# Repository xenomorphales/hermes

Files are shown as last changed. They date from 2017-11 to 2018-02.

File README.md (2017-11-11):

# Hermes

Hermes is a rolling base board that drives motors and gets feedback from encoders, IR distance sensors and limit switches.

Warning: before opening any file from this KiCad project, make sure to have a path set in KiCad (Preferences > Configure Paths) named XENOCAD and pointing to the KiCad subdirectory of our [xenocad repository](https://github.com/xenomorphales/xenocad).

[Back to our main project](https://github.com/xenomorphales/xenomorphales)

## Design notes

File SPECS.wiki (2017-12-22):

== Devices ==

{|
!  Device !! Quantity !! Links !! Comment
|-
| Main board
| 1
| [https://www.pjrc.com/store/teensy32.html Board]
| Teensy 3.2
|-
| Motor 30A fuse
| 1
| [https://www.mouser.fr/ProductDetail/Bussmann-Eaton/BK-ABC-V-30-R/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 Axial fuse]
|
|-
| 5V regulator
| 1
| [https://www.mouser.fr/ProductDetail/Murata-Power-Solutions/OKI-78SR-5-15-W36-C/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 Regulator]
| Murata OKI78SR5/1.5W36C
|-
| Regulator 1A fuse
| 1
| [https://www.mouser.fr/ProductDetail/Bussmann-Eaton/BK-GMA-1-R/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 Fuse] <br/>
[https://www.mouser.fr/ProductDetail/Littelfuse/64600001003/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 Fuse holder]
|
|-
| Encoder
| 2
| [http://www.robotshop.com/eu/fr/encodeur-rotatif-6mm-1024-p-r.html Encoder]
|
|-
| Motor driver
| 2 channels
|
[https://www.pololu.com/product/708 Driver] <br/>
[http://www.francerobotique.com/moteurs-classiques/567-moteur-metal-planetaire-premium-hd-12v-612rpm-avec-encodeur-art0567-servocitypoids-330g-rapport-de-reduction-14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 Motors]
|
|-
| Limit switch
| 4
|
| With debounce system
|-
| GP2
| 6
|
|
|-
| CAN
| 1
| [https://www.mouser.fr/ProductDetail/Texas-Instruments/SN65HVD232DR/?qs=sGAEpiMZZMuo%252bmZx5g6tFL5kWJ52EgZi Transceiver]
|
|-
| UART
| 2
|
|
|-
| I2C
| 1
|
|
|-
| Debug LED
| 3
| [https://www.mouser.fr/ProductDetail/Kingbright/AP3216CGCK/?qs=VdjlWU%2FzoOG1eeDl%2FnjAXA%3D%3D LED]
| Green LED
|-
| Pull
| 1
|
| With debounce system
|-
| Power LED
| 2
| [https://www.mouser.fr/ProductDetail/Kingbright/AP3216SURCK/?qs=sGAEpiMZZMseGfSY3csMkfJS7xWFNN5n33Jv6PCAEQU%3D LED]
| Red LED (one for +15V, one for +5V)
|-
|}

== Pin mapping ==

{|
!  Board pin !! µC pin index !! µC pin name !! Mode        !! I/O !! Feature
|-
|  0         || 39           || PTB16       || UART0_RX    || I   || UART 0 input
|-
|  1         || 40           || PTB17       || UART0_TX    || O   || UART 0 output
|-
|  2         || 57           || PTD0        || PTD0        || I   || Pull
|-
|  3         || 28           || PTA12       || CAN0_TX     || O   || CAN ouput
|-
|  4         || 29           || PTA13       || CAN0_RX     || I   || CAN input
|-
|  5         || 64           || PTD7        || PTD7        || I   || Limit switch 1
|-
|  6         || 61           || PTD4        || PTD4        || I   || Limit switch 2
|-
|  7         || 59           || PTD2        || PTD2        || I   || Limit switch 3
|-
|  8         || 60           || PTD3        || PTD3        || I   || Limit switch 4
|-
|  9         || 46           || PTC3        || UART1_RX    || I   || UART 1 input
|-
|  10        || 49           || PTC4        || UART1_TX    || O   || UART 1 output
|-
|  11        || 51           || PTC6        || PTC6        || O   || LED Debug0
|-
|  12        || 52           || PTC7        || PTC7        || O   || LED Debug1
|-
|  13        || 50           || PTC5        || PTC5        || O   || LED Debug2 ; On-board LED
|-
|  14        || 58           || PTD1        || ADC0_SE5b   || I   || GP2 1
|-
|  15        || 43           || PTC0        || PTC0        || I   || Motor driver 1 diag input
|-
|  16        || 35           || PTB0        || FTM1_QD_PHA || I   || Encoder 1 phase A
|-
|  17        || 36           || PTB1        || FTM1_QD_PHB || I   || Encoder 1 phase B
|-
|  18        || 38           || PTB3        || I2C0_SDA    || I/O || I2C data
|-
|  19        || 37           || PTB2        || I2C0_SCL    || I/O || I2C clock
|-
|  20        || 62           || PTD5        || ADC0_SE6b   || I   || GP2 2
|-
|  21        || 63           || PTD6        || ADC0_SE7b   || I   || GP2 3
|-
|  22        || 44           || PTC1        || FTM0_CH0    || O   || Motor driver 1 PWM output
|-
|  23        || 45           || PTC2        || FTM0_CH1    || O   || Motor driver 2 PWM output
|-
|  A10       || 9            || ADC0_DP0    || ---         || --- || ---
|-
|  A11       || 10           || ADC0_DM0    || ---         || --- || ---
|-
|  A12       || 11           || ADC0_DP3    || ---         || --- || ---
|-
|  A13       || 12           || ADC0_DM3    || ---         || --- || ---
|-
|  A14       || 18           || DAC0        || ---         || --- || ---
|-
|  24        || 27           || PTA5        || PTA5        || O   || Motor driver 1 IN_A output
|-
|  25        || 42           || PTB19       || FTM2_QD_PHB || I   || Encoder 2 phase B
|-
|  26        || 2            || PTE1        || PTE1        || O   || Motor driver 2 IN_A output
|-
|  27        || 54           || PTC9        || ADC1_SE5b   || I   || GP2 4
|-
|  28        || 53           || PTC8        || PTC8        || I   || Motor driver 2 diag input
|-
|  29        || 55           || PTC10       || ADC1_SE6b   || I   || GP2 5
|-
|  30        || 56           || PTC11       || ADC1_SE7b   || I   || GP2 6
|-
|  31        || 1            || PTE0        || PTE0        || O   || Motor driver 2 IN_B output
|-
|  32        || 41           || PTB18       || FTM2_QD_PHA || I   || Encoder 2 phase A
|-
|  33        || 26           || PTA4        || PTA4        || O   || Motor driver 1 IN_B output
|}

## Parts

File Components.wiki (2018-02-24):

== Components for Hermes 2 ==

=== Components for the board itself ===

{|
! Description !! Quantity !! Supplier
|-
| Resistor SMD1206 22Ω 0.25W
| 4
| [https://www.mouser.com/productdetail/603-rc1206fr-0722rl Mouser]
|-
| Resistor SMD1206 120Ω 0.25W
| 3
| [https://www.mouser.com/productdetail/603-rc1206fr-07120rl Mouser]
|-
| Resistor SMD1206 1.4kΩ 0.25W
| 1
| [https://www.mouser.com/productdetail/603-rc1206fr-071k4l Mouser]
|-
| Resistor SMD1206 2kΩ 0.25W
| 2
| [https://www.mouser.com/productdetail/603-rc1206fr-072kl Mouser]
|-
| Resistor SMD1206 6kΩ 0.25W
| 1
| [https://www.mouser.com/productdetail/603-rc1206fr-076k04l Mouser]
|-
| Resistor SMD1206 10kΩ 0.25W
| 14
| [https://www.mouser.com/productdetail/603-rc1206fr-0710kl Mouser]
|-
| Resistor SMD1206 18kΩ 0.25W
| 5
| [https://www.mouser.com/productdetail/603-rc1206fr-0718kl Mouser]
|-
| Resistor SMD1206 20kΩ 0.25W
| 6
| [https://www.mouser.com/productdetail/603-rc1206fr-0720kl Mouser]
|-
| Resistor SMD1206 100kΩ 0.25W
| 5
| [https://www.mouser.com/productdetail/603-rc1206fr-07100kl Mouser]
|-
| Ceramic capacitor SMD1206 100nF 50V
| 14
| [https://www.mouser.com/productdetail/963-umk316b7104kd-t Mouser]
|-
| Ceramic capacitor SMD1206 1µF 25V
| 6
| [https://www.mouser.com/productdetail/963-tmk316b7105kl-t Mouser]
|-
| Ceramic capacitor SMD1206 10µF 25V
| 9
| [https://www.mouser.com/productdetail/963-tmk316ab7106kl-t Mouser]
|-
| Green LED SMD1206
| 3
| [https://www.mouser.com/productdetail/604-ap3216cgck Mouser]
|-
| Red LED SMD1206
| 2
| [https://www.mouser.com/productdetail/604-ap3216surck Mouser]
|-
| Fuse holder 6.3A 250V
| 1
| [https://www.mouser.com/productdetail/576-64600001223 Mouser]
|-
| Fuse 3AG 30A 125VDC fast-acting, axial mounting
| 1
| [https://www.mouser.com/productdetail/504-bk-abc-v-30-r Mouser]
|-
| CAN transceiver
| 1
| [https://www.mouser.com/productdetail/595-sn65hvd232dr Mouser]
|-
| 5V switching regulator
| 1
| [https://www.mouser.com/productdetail/580-oki-78sr-5-1.5-w36-c Mouser]
|-
| Teensy 3.2
| 1
| [https://snootlab.com/963-teensy-32-usb-en.html Snootlab]
|-
| Break away headers for the Teensy's side pins
| 2
| [https://snootlab.com/connectors/305-break-away-headers-16-pins-strip.html Snootlab]
|-
| Break away sockets for the Teensy's side pins
| 2
| [https://www.mouser.com/productdetail/517-929974-01-14-rk Mouser]
|-
| Teensy 3.2 header kit (for the 2x7 pins SMD header)
| 1
| [https://snootlab.com/sparkfun/1190-teensy-32-header-kit-en.html Snootlab]
|-
| Break away socket for the Teensy's underneath pins
| 1
| [https://www.mouser.com/productdetail/517-929975-01-07-rk Mouser]
|-
| Motor driver carrier
| 1
| [https://www.pololu.com/product/708 Pololu]
|-
| Break away socket for the motor driver carrier
| 1
| [https://www.mouser.fr/productdetail/517-929974-01-15-rk Mouser]
|-
| Male right angle power connector
| 2
| [https://www.mouser.com/productdetail/798-df22-3p-7.92ds05 Mouser]
|-
| Vertical male connector 2.54mm 2 pins
| 5
| [https://www.mouser.com/productdetail/538-22-27-2021 Mouser]
|-
| Vertical male connector 2.54mm 3 pins
| 11
| [https://www.mouser.com/productdetail/538-22-27-2031 Mouser]
|-
| Vertical male connector 2.54mm 4 pins
| 2
| [https://www.mouser.com/productdetail/538-22-27-2041 Mouser]
|-
|}

=== Other components (wires, connectors, supplies...) ===

{|
! Description !! Quantity !! Supplier
|-
| Fuse 5mm x 20mm 1A 250VAC fast-acting
| 1
| [https://www.mouser.com/productdetail/504-bk-gma-1-r Mouser]
|-
| XT60 connectors pack (5 pairs)
| 1
| [https://hobbyking.com/en_us/nylon-xt60-connectors-male-female-5-pairs-genuine.html HobbyKing]
|-
| Female power connector
| 2
| [https://www.mouser.com/productdetail/798-df22-3s-7.92c28 Mouser]
|-
| Female power connector contact
| 6
| [https://www.mouser.com/productdetail/798-df22-1416scf Mouser]
|-
| Power connector retainer
| 2
| [https://www.mouser.com/productdetail/798-df22-3rs-p-7.92 Mouser]
|-
| Vertical female connector 2.54mm 2 pins
| 5
| [https://www.mouser.com/productdetail/538-22-01-2025 Mouser]
|-
| Vertical female connector 2.54mm 3 pins
| 11
| [https://www.mouser.com/productdetail/538-22-01-2035 Mouser]
|-
| Vertical female connector 2.54mm 4 pins
| 2
| [https://www.mouser.com/productdetail/538-22-01-2045 Mouser]
|-
| Female connector contact
| 51
| [https://www.mouser.com/productdetail/538-08-50-0114 Mouser]
|-
| 14AWG black power wire
| 3
| [https://www.mouser.com/productdetail/650-400R0111-14-0 Mouser]
|-
| 14AWG white power wire
| 3
| [https://www.mouser.com/productdetail/650-400R0111-14-9 Mouser]
|-
|}

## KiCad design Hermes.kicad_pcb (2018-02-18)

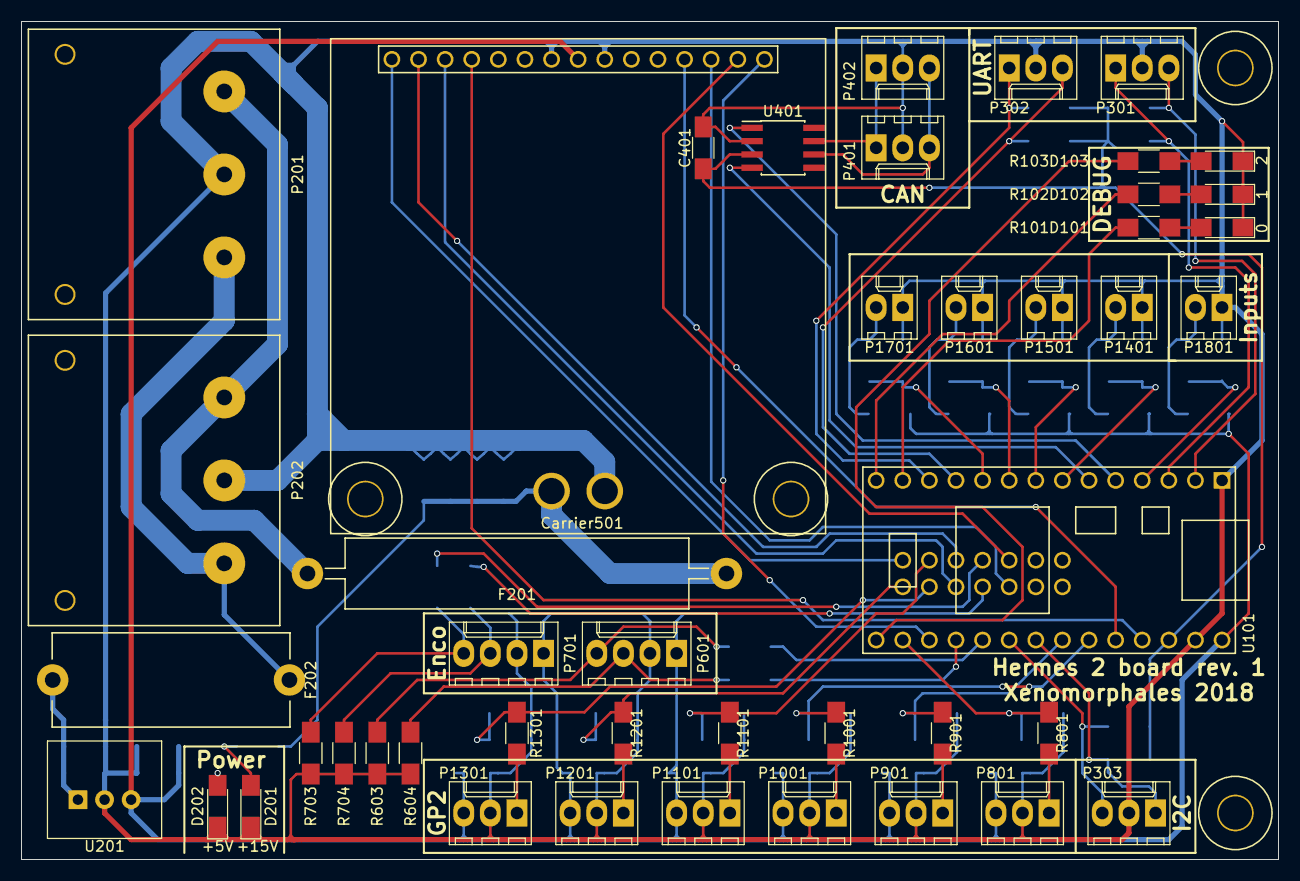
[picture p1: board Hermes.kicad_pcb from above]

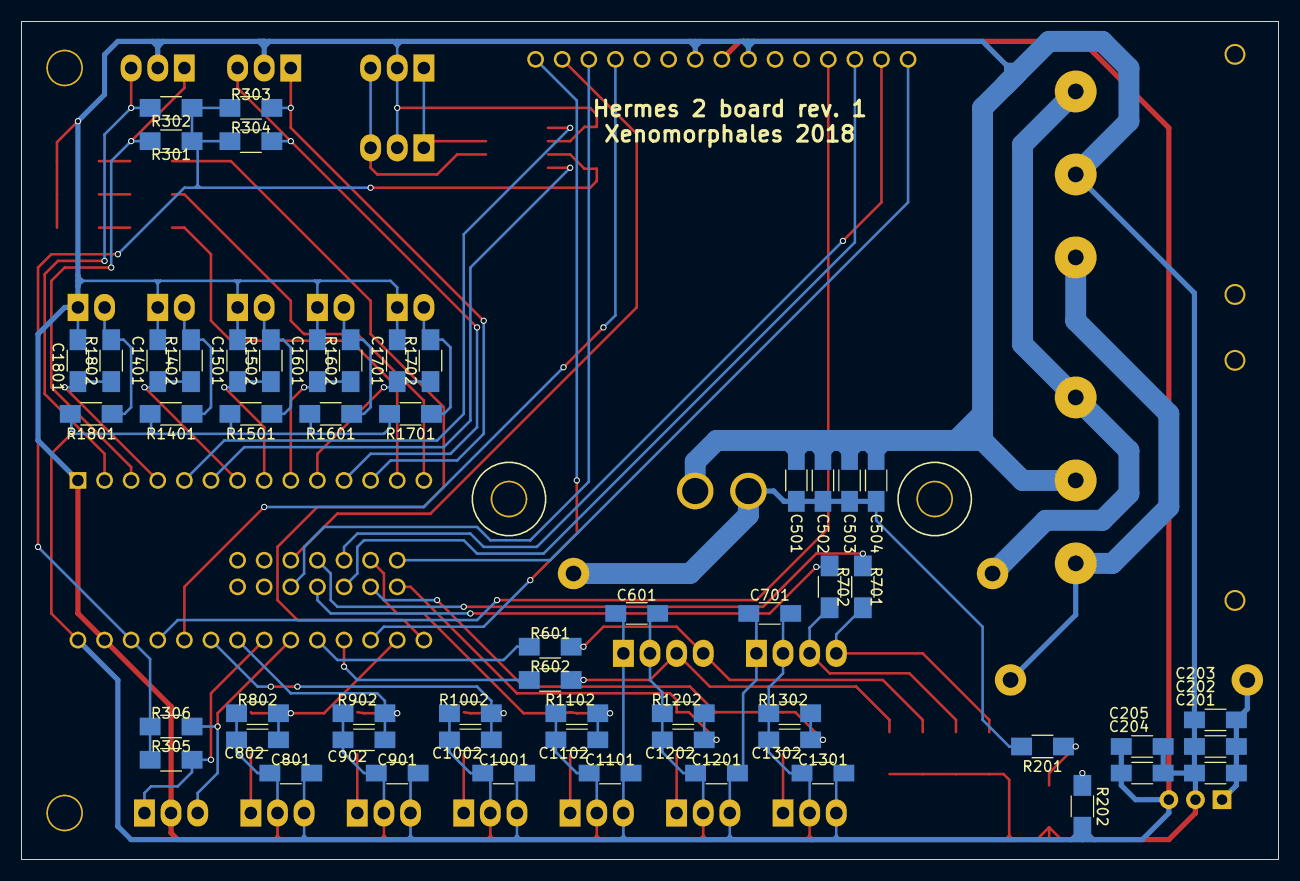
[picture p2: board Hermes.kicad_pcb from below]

Board: 2 copper layers, 120.0 x 80.0 mm, 101 parts (56 on the bottom side), 63 nets.

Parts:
C201, C501, C503, C801, C901, C1001, C1101, C1201, C1301: 10µF; C_1206_HandSoldering
C202, C203, C205, C401, C502, C504, C601, C701, C802, C902, C1002, C1102, C1202, C1302: 100nF; C_1206_HandSoldering
C204, C1401, C1501, C1601, C1701, C1801: 1µF; C_1206_HandSoldering
Carrier501: Pololu_Dual_VNHxSP30_Motor_Driver_Carrier; Pololu_Dual_VNHxSP30_Motor_Driver_no_output
D101, D102, D103: LED_Debug; LED_1206_HandSoldering
D201: LED_15V; LED_1206_HandSoldering
D202: LED_5V; LED_1206_HandSoldering
F201: FUSE 30A; Fuse_Eaton-ABC_20A+_Axial
F202: FUSE 1A; Fuseholder_Littlefuse-646
P201, P202: Power_IO; Hirose_DF22-03P-7.92DS_03x7.92mm_Angled
P301, P302: UART_IO; Molex_KK-6410-03_03x2.54mm_Straight
P303: I2C_IO; Molex_KK-6410-03_03x2.54mm_Straight
P401, P402: CAN_IO; Molex_KK-6410-03_03x2.54mm_Straight
P601, P701: Encoder_IO; Molex_KK-6410-04_04x2.54mm_Straight
P801, P901, P1001, P1101, P1201, P1301: GP2_IO; Molex_KK-6410-03_03x2.54mm_Straight
P1401, P1501, P1601, P1701, P1801: DebouncedInput_IO; Molex_KK-6410-02_02x2.54mm_Straight
R101, R102, R103: 120Ω; R_1206_HandSoldering
R201: 6kΩ; R_1206_HandSoldering
R202: 1.4kΩ; R_1206_HandSoldering
R301, R302, R303, R304, R603, R604, R703, R704, R801, R901, R1001, R1101, R1201, R1301: 10kΩ; R_1206_HandSoldering
R305, R306: 2kΩ; R_1206_HandSoldering
R601, R602, R701, R702: 22Ω; R_1206_HandSoldering
R802, R902, R1002, R1102, R1202, R1302: 20kΩ; R_1206_HandSoldering
R1401, R1501, R1601, R1701, R1801: 100kΩ; R_1206_HandSoldering
R1402, R1502, R1602, R1702, R1802: 18kΩ; R_1206_HandSoldering
U101: Teensy3.2; Teensy30_31_32_LC_sides_bottom
U201: OKI78SR5/1.5W36C; OKI-78SR-Vertical
U401: SN65HVD232; SOIC-8_3.9x4.9mm_Pitch1.27mm

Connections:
/+3.3V: C401.1, R301.1, R302.1, R303.1, R304.1, R305.1, R306.1, U101.31, U401.3
/+5V: C204.1, C205.1, C601.1, C701.1, C801.2, C901.2, C1001.2, C1101.2, C1201.2, C1301.2, Carrier501.8, P601.1, P701.1, P801.3, P901.3, P1001.3, P1101.3, P1201.3, P1301.3, R202.1, R1401.1, R1501.1, R1601.1, R1701.1, R1801.1, U101.33, U201.3
/+15V: C501.1, C502.1, C503.1, C504.1, Carrier501.19, F201.2, R201.1
/CAN_RX: U101.6, U401.4
/CAN_TX: U101.5, U401.1
/DIAG_1: Carrier501.1, U101.22
/DIAG_2: Carrier501.15, U101.44
/ENC_1_A: R602.1, U101.23
/ENC_1_B: R601.1, U101.24
/ENC_2_A: R702.1, U101.48
/ENC_2_B: R701.1, U101.41
/GND: C201.2, C202.2, C203.2, C204.2, C205.2, C401.2, C501.2, C502.2, C503.2, C504.2, C601.2, C701.2, C801.1, C802.1, C901.1, C902.1, C1001.1, C1002.1, C1101.1, C1102.1, C1201.1, C1202.1, C1301.1, C1302.1, C1401.2, C1501.2, C1601.2, C1701.2, C1801.2, Carrier501.7, Carrier501.9, Carrier501.18, D101.1, D102.1, D103.1, D201.1, D202.1, P201.2, P202.2, P301.2, P302.2, P303.2, P401.2, P402.2, P601.2, P701.2, P801.2, P901.2, P1001.2, P1101.2, P1201.2, P1301.2, P1401.1, P1501.1, P1601.1, P1701.1, P1801.1, R603.1, R604.1, R703.1, R704.1, R802.1, R902.1, R1002.1, R1102.1, R1202.1, R1302.1, U101.1, U101.32, U201.2, U401.2
/GP2_1_Signal: C802.2, R801.1, R802.2, U101.21
/GP2_2_Signal: C902.2, R901.1, R902.2, U101.27
/GP2_3_Signal: C1002.2, R1001.1, R1002.2, U101.28
/GP2_4_Signal: C1102.2, R1101.1, R1102.2, U101.43
/GP2_5_Signal: C1202.2, R1201.1, R1202.2, U101.45
/GP2_6_Signal: C1302.2, R1301.1, R1302.2, U101.46
/IN_A_1: Carrier501.2, U101.40
/IN_A_2: Carrier501.14, U101.42
/IN_B_1: Carrier501.3, U101.49
/IN_B_2: Carrier501.13, U101.47
/LED_Debug0: R101.1, U101.13
/LED_Debug1: R102.1, U101.14
/LED_Debug2: R103.1, U101.20
/LimitSwitch_1_Signal: C1401.1, R1402.1, U101.7
/LimitSwitch_2_Signal: C1501.1, R1502.1, U101.8
/LimitSwitch_3_Signal: C1601.1, R1602.1, U101.9
/LimitSwitch_4_Signal: C1701.1, R1702.1, U101.10
/PWM_1: Carrier501.4, U101.29
/PWM_2: Carrier501.12, U101.30
/PullSignal: C1801.1, R1802.1, U101.4
/SCL: P303.1, R305.2, U101.26
/SDA: P303.3, R306.2, U101.25
/UART0_RX: P301.3, R302.2, U101.2
/UART0_TX: P301.1, R301.2, U101.3
/UART1_RX: P302.3, R304.2, U101.11
/UART1_TX: P302.1, R303.2, U101.12
unnamed: C201.1, C202.1, C203.1, F202.2, U201.1
unnamed: D101.2, R101.2
unnamed: D102.2, R102.2
unnamed: D103.2, R103.2
unnamed: D201.2, R201.2
unnamed: D202.2, R202.2
unnamed: F201.1, P201.3, P202.3
unnamed: F202.1, P201.1, P202.1
unnamed: P401.1, P402.1, U401.7
unnamed: P401.3, P402.3, U401.6
unnamed: P601.3, R602.2, R604.2
unnamed: P601.4, R601.2, R603.2
unnamed: P701.3, R702.2, R704.2
unnamed: P701.4, R701.2, R703.2
unnamed: P801.1, R801.2
unnamed: P901.1, R901.2
unnamed: P1001.1, R1001.2
unnamed: P1101.1, R1101.2
unnamed: P1201.1, R1201.2
unnamed: P1301.1, R1301.2
unnamed: P1401.2, R1401.2, R1402.2
unnamed: P1501.2, R1501.2, R1502.2
unnamed: P1601.2, R1601.2, R1602.2
unnamed: P1701.2, R1701.2, R1702.2
unnamed: P1801.2, R1801.2, R1802.2

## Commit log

2017-11-11 Adding Hermes 1 files.
    [Com.sch, Driver.sch, Encoder.sch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]
2017-11-11 Adding Hermes 2 schematic files.
    [BasicCom.sch, CANCom.sch, DebouncedInput.sch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]
2017-11-18 Moving the 5V regulator to the non-emergency-stop-guarded +15V and adding a fuse for it.
    [Power.sch]
2017-12-22 Changing I2C pull-up resistors to 2kohm to allow I2C bus to work in fast-mode.
    [BasicCom.sch]
2017-12-22 Rearranging encoder sheet so GND is at the bottom and power supply at the top.
    [Encoder.sch]
2017-12-22 Rewording debounced input sheet's comment.
    [DebouncedInput.sch]
2017-12-22 Changing some value fields on the schematics for a better grouped_csv BOM generation.
    [BasicCom.sch, CANCom.sch, DebouncedInput.sch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]
2017-12-22 Changing the LM7805 for a OKI78SR5/1.5W36C since it would heat way too much with a +15V input.
    [Power.sch]
2017-12-23 Replacing the 5V regulator's input 220nF capacitor with two 100nF capacitors.
    [Power.sch]
2017-12-23 Updating the schematic's annotations.
    [BasicCom.sch, CANCom.sch, DebouncedInput.sch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]
2017-12-31 Adding BOM.
    Just a few external components (like wires) are missing.
2018-01-01 Updating BOM.
    Still a few components are missing.
2018-01-13 Updating BOM.
    - Adding 14AWG power wires
    - Changing female power connector contact for 14AWG wires
2018-01-13 Setting the schematic's footprints.
    [BasicCom.sch, CANCom.sch, DebouncedInput.sch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]
2018-02-17 Fixing driver sheet after Pololu Dual VNHxSP30 Motor Driver schema update on xenocad.
    [Driver.sch]
2018-02-18 Adding the PCB layout.
    [Hermes.kicad_pcb]
2018-02-24 Updating BOM.
    Changing break away socket for the Teensy's underneath pins from 8 positions to 14.
